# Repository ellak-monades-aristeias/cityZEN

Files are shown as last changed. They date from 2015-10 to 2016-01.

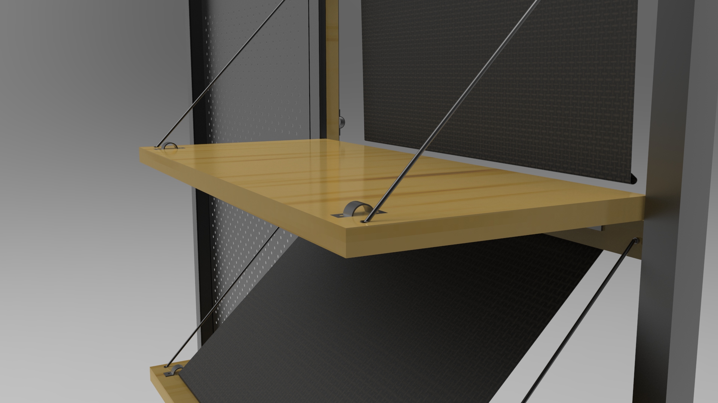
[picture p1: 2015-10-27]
bench/3d model/φωτορεαλιστικη απεικονιση/render.39.jpg

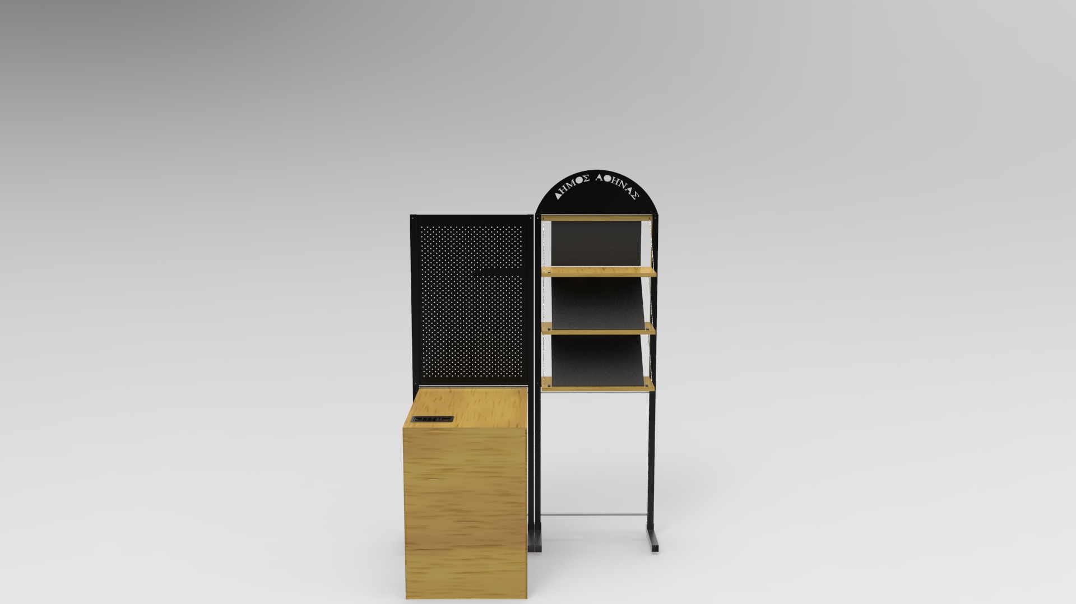
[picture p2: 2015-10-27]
bench/3d model/φωτορεαλιστικη απεικονιση/render.49.jpg

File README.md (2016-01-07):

# cityZEN

## Idea description

It's quite common to encounter hawkers on the streets, merchandising hand crafted objects, such us jewellery, vases or paintings. Using their craftsmanship skills is often a way for unemployed people with little if any income to increase their earnings. Unfortunately this activity is considered illegal and the legalisation surrounding it requires complex bureaucratic processes and fees, making it essentially inaccessible for them.

The legislators do not consider the aforementioned target group to be desirable, but they rather try to eliminate any such type of merchandising in fear of extensive profiteering from mischievous behaviour. The unfair competition between the pedlars and shop owners, the unregistered earnings of the pedlars, as well as the distortion of the cityscapes are, amongst others, the main reasons which increase the complexity of this way of merchandising. Identifying this gap sparked the idea for the creation of a system that allows unemployed people with craftsmanship skills to reach the market easily, in a way that can benefit both the merchants and the municipality. 

CityZEN proposes, on the one hand, a municipal service responsible for all legal, space, technical and curating issues, including the management of the merchants who use the service and the setting up the stalls. On the other hand, this project proposes a design of a versatile bench to unify the aesthetics and enable the beneficiaries to showcase their products.

The envisioned benefits are multifaceted: For the unemployed this service can help not only to increase their income but also to consider alternative careers. It is important to mention that the service is not intended to be provided for hawkers with high earnings but rather as an initial support for them to grow out of illegality and transform into established merchants. At the same time, the municipalities' identity is branded, the aesthetics of the cityscapes are improved and illegal merchandising can be better controlled.

## Η ιδέα

Πολλές φορές στις πόλεις μας τυχαίνει να βλέπουμε μικροπωλητές στα πλαϊνά των
πεζοδρόμων και των πλατειών να εμπορεύονται χειρότεχνα αντικείμενα, όπως
κοσμήματα, βαζάκια, πίνακες ζωγραφικής και άλλα παρόμοια είδη. Πρόκειται
συνήθως για ανθρώπους με χαμηλά ή μηδενικά εισοδήματα, συνήθως άνεργους, που
έχουν κάποιο ταλέντο και γνώσεις στην δημιουργία έργων χειροτεχνίας και
αναζητούν τρόπο να εκμεταλλευτούν την ικανότητά τους αυτήν προς όφελός τους.

Δυστυχώς η κοινωνία μας καθιστά ιδιαίτερα δύσκολο σε αυτούς τους ανθρώπους να
το πράξουν αυτό. Η πώληση αυτών των αγαθών σε δημόσιους χώρους είναι
παράνομη και για να νομιμοποιηθεί χρειάζονται επίπονες γραφειοκρατικές
διαδικασίες καθώς και καταβολή δυσμενών φόρων που καθιστούν το όλο εγχείρημα
μη συμφέρων, δεδομένου ότι η ποσότητα των πωλούμενων αντικειμένων είναι μικρή.

Η νομοθεσία μας καθιστά αυτό το είδος εμπορίου παράνομο, όμως, με αιτία τα εξής.
Καταρχήν, το γεγονός ότι επιτήδειοι θα μπορούσαν σε διαφορετική περίπτωση να
εκμεταλλευτούν δημόσιους χώρους για να έχουν **ανεξέλεγκτα κέρδη** χωρίς το
βάρος της ενοικίασης χώρου. Κατά δεύτερον, τον **αθέμιτο ανταγωνισμό** που
δημιουργείται μεταξύ των μικροπωλητών και των καταστημάτων που βρίσκονται
πλησίον τους, σε βάρος πάντα των καταστημάτων. Κατά τρίτον, την 
**αλλοίωση της εικόνας της πόλης**, που προκύπτει από το γεγονός ότι οι
πωλητές αυτοί χρησιμοποιούν αυτοσχέδιους τρόπους έκθεσης των εμπορευμάτων
τους, κάνοντας χρήση χαλιών, μουσαμάδων, χαρτόκουτων, κουβάδων, και άλλων
παρεμφερών αντικειμένων, σε διατάξεις ακανόνιστες, χωρίς να δίνεται καμία
προσοχή στην αισθητική.

Η πρότασή μας επιχειρεί να δώσει μια βοήθεια σε αυτούς τους μικροπωλητές,
λαμβάνοντας υπόψιν τα παραπάνω προβλήματα που δημιουργούνται από την
δραστηριότητά τους και δίνοντας λύσεις για καθένα από αυτά μέσα σε ένα πλαίσιο
που είναι και νόμιμο αλλά και εξίσου εύκολο και συμφέρων για αυτούς. Η πρόταση
αυτή αποτελείται από μια δημοτική υπηρεσία η οποία είναι υπεύθυνη για την ρύθμιση
όλων των νομικών, χωροτεχνικών και διαδικαστικών θεμάτων που αφορούν το
στήσιμο πάγκων μικροπωλητών αποκλειστικά από ανέργους, καθώς και από το
σχέδιο ενός πολυμορφικού πάγκου που στόχο έχει να δώσει ομοιόμορφη αισθητική και
να αποφέρει οφέλη για τον δήμο.

Τα οφέλη από την χρησιμοποίηση της λύσης μας είναι πολύπλευρα. Για τους
ανέργους, η υπηρεσία αυτή μπορεί να βοηθήσει στην αύξηση του εισοδήματός τους,
αλλά παράλληλα και στην ενεργοποίησή τους να κάνουν κάτι παραγωγικό με
προοπτική εξέλιξης σε κανονική επιχείρηση. Να σημειωθεί εδώ ότι η υπηρεσία μας
είναι σχεδιασμένη έτσι ώστε να σταματάει να παρέχεται σε μικροπωλητές που
επιτυγχάνουν μεγάλα κέρδη, ωθώντας τους έτσι να εξελιχθούν σε κανονικούς επιχειρηματίες. 
Από την άλλη, για τους δήμους δίνεται η δυνατότητα προβολής μέσα
από το branding που ενσωματώνεται στην κατασκευή, αναβαθμίζεται η αισθητική της
πόλης και επιπλέον δίνεται δυνατότητα καλύτερου ελέγχου αυτού του είδους
επιχειρηματικής δραστηριότητας έτσι ώστε να μην δημιουργούνται ούτε προβλήματα
εκμετάλλευσης αλλά ούτε και αθέμιτου ανταγωνισμού. Επιπλέον, οι πάγκοι αυτοί
μπορούν να χρησιμοποιηθούν και σε άλλα εγχειρήματα, όπως οι λαϊκές αγορές,
επιφέροντας και πάλι αντίστοιχα οφέλη στις δημοτικές αρχές.

## Περιγραφή σχεδίου

### Υπηρεσία

Η προτεινόμενη υπηρεσία λειτουργεί ως εξής. 

1. Αρχικά, ο ενδιαφερόμενος άνεργος πολίτης απευθύνεται στον οικείο του δήμο
προκειμένου να εγγραφεί στην υπηρεσία.

2. Όντας εγγεγραμμένος, αποκτά το δικαίωμα να χρησιμοποιήσει έναν από τους
πάγκους πώλησης της υπηρεσίας. Για να αποκτήσει έναν πάγκο χρειάζεται να
κάνει αίτηση στον δήμο, προσκομίζοντας μια λίστα με τα αντικείμενα τα οποία
ενδιαφέρεται να πουλήσει, αναγραφόμενα με είδος και ακριβή ποσότητα.

3. Στην συνέχεια, ο δήμος από την πλευρά του εγκρίνει ή απορρίπτει το αίτημα.

4. Μετά την έγκριση, παρέχεται στον ενδιαφερόμενο ένας πάγκος, καθώς και
πρόσβαση στην διαδικτυακή εφαρμογή της υπηρεσίας, μέσω της οποίας ο
ενδιαφερόμενος μπορεί να εντοπίσει τις διαθέσιμες επιτρεπόμενες τοποθεσίες
εγκατάστασης του πάγκου και να κάνει κράτηση σε κάποια από αυτές. Η
κράτηση αυτή προτείνεται να έχει ένα ανώτατο συνολικό χρονικό όριο 25 ωρών
την εβδομάδα, προκειμένου να δίνεται ευκαιρία και σε άλλους συμμετέχοντες να
χρησιμοποιήσουν την ίδια τοποθεσία.

5. Κατά την πώληση, οι μικροπωλητές οφείλουν να χρησιμοποιούν την
ενσωματωμένη ταμειακή μηχανή του πάγκου για να καταγράφουν τα ποσά που
λαμβάνουν.

6. Με βάση την χρηματική απόδοση (που ορίζεται ως κέρδος ανά χρόνο), το
δικαίωμα χρήσης της υπηρεσίας μπορεί να αναστέλλεται στις περιπτώσεις όπου
α) υπάρχει πολύ μικρή απόδοση ή β) υπάρχει πολύ μεγάλη απόδοση, στην οποία
περίπτωση η υπηρεσία δίνει κάποια περαιτέρω βοήθεια στον μικροπωλητή για να
ανοίξει κανονική επιχείρηση. Με αυτόν τον τρόπο δίνεται κίνητρο στον
μικροπωλητή να προσπαθήσει για ένα καλό αποτέλεσμα. Παράλληλα βέβαια, για
την αποφυγή εισαγωγής ψεύτικων στοιχείων στην ταμειακή μηχανή, επιβάλλεται
είσπραξη ενός μικρού ποσοστού 5% των κερδών από τον δήμο, πράγμα το οποίο
παράλληλα καλύπτει κάποια λειτουργικά έξοδα της υπηρεσίας.

### Πάγκος

Ο πάγκος αποτελείται από 4 αποσπώμενα μέρη τα οποία μπορούν να συνδυαστούν σε
διάφορους σχηματισμούς.

Αριστερά υπάρχει μια ξύλινη επίπεδη κατασκευή η οποία στέκεται όρθια με μεταλλικά
στηρίγματα και πόδια και με ράφια τα οποία ανοίγουν. Τα ράφια διαθέτουν στο
πίσω μέρος ένα ελαστικό παραβάν το οποίο μπορεί να μετατοπιστεί από την κάτω
του μεριά έτσι ώστε να δημιουργήσει ένα επικλινές για προβολή βιβλίων ή
αντίστοιχων αντικειμένων.

Δεξιά αυτού του μέρους υπάρχει μια διάτρητη μεταλλική επιφάνεια ίδιων διαστάσεων
με το προηγούμενο μέρος η οποία στηρίζεται με τον ίδιο τρόπο και στην οποία οι
χρήστες μπορούν να προσαρμόσουν εξαρτήματα για διάφορες χρήσεις.
Στο πάνω μέρος προσαρμόζεται μια ημικυκλική επιφάνεια, επίσης μεταλλική, η οποία
φέρει το λογότυπο του δήμου σχεδιασμένο με τρύπες πάνω στην επιφάνεια. Το μέρος
αυτό διατίθεται σε 2 διαστάσεις, ενα μικρό που μπορεί να συνδυαστεί είτε με το μέρος
των ραφιών είτε με την διάτρητη επιφάνεια, και ένα μεγάλο που συνδυάζεται και με
τα 2 ταυτόχρονα και τα δένει μεταξύ τους.

Τέλος, στο κάτω μέρος ενός εκ των 2 κάτω μερών προσαρμόζεται ένας επίπεδος
πάγκος. Μέσα σε αυτόν ενσωματώνεται και η ταμιακή μηχανή, σε περίπτωση που η
κατασκευή πρόκειται να χρησιμοποιηθεί με βάση την υπηρεσία της πρότασής μας.

Το σχέδιο αυτό επιτρέπει μεγάλη προσωπικοποίηση, τόσο μέσω του σχεδιασμού του με
βάση την χρήση διάφορων μερών καθώς και μέσω του αυτοσχεδιασμού των χρηστών
του.

### Ταμειακή μηχανή

Η διεπαφή της ταμειακής μηχανής επιτυγχάνεται με μια μικρή οθόνη TFT και ένα
πληκτρολόγιο μεμβράνης. Μέσα από την εφαρμογή δίνεται στον χρήστη η
δυνατότητα να εκτελέσει δυο λειτουργίες. Πρώτον, να εισάγει μια καινούρια πώληση
που μόλις έκανε και δεύτερον, να εξετάσει το ιστορικό πωλήσεων και να λάβει
πληροφορίες για την απόδοσή του.

Οι πληροφορίες αποθηκεύονται όλες σε μια προσβάσιμη και αφαιρούμενη SD card η
οποία εξετάζεται από τις δημοτικές αρχές ανά τακτά χρονικά διαστήματα.
Η μηχανή λειτουργεί με μπαταρίες, οι οποίες θα πρέπει να αλλάζονται κάθε περίπου 3
μήνες από τις δημοτικές αρχές.

## Πλοήγηση στο repository

- bench/ | φάκελος με τα σχέδια που αφορούν το έπιπλο-πάγκο
 - 3d model/
     - Φωτορεαλιστική απεικόνιση | εικόνες του αντικειμένου από διάφορες οπτικές
     - finalbench3dmodel.3dm     | το τελικό 3d model
     - render.bip                | keyshot file από το οποίο παράχθηκαν τα render
 - Files for 3d print/
     - Σφυχτήρας συρματόσχοινου.{3dm,stl} | αρχείο για 3d εκτύπωση πλαστικών κομματιών
                                            που συγκρατούν το συρματόσχοινο
 - Files for lasercut/
     - Bench desk.{ai,svg,pdf,dwg} | αρχεία για την κοπή του ξύλου του πάγκου
     - Box for electronics.{ai,svg,pdf,dwg}  | αρχεία κοπής των μερών του κουτιού
                                               για τα ηλεκτρονικά
     - File for the drawers.{ai,svg,pdf,dwg} | αρχεία κοπής των ραφιών
     - Metal plate lasercut_label_keyboard   | αρχείο κοπής μεταλλικής πινακίδας
                                               καθώς και του πληκτρολογίου
  - Πληκτρολόγιο μεμβράνης/
     - Πληκτρολόγιο μεμβράνης.{ai,pdf,svg}   | πρόταση κατασκευής πληκτρολογίου μεμβράνης
  - read me.odt      | πληροφορίες για τα υλικά και τη συντήρηση της κατασκευής
  - Οδηγίες κατασκευής.{ai,svg,pdf}  | φύλλο οδηγιών κατασκευής ενός πρωτοτύπου
- cash register/ | φάκελος με τα σχέδια που αφορούν την ηλεκτρονική ταμιακή μηχανή
 - electronics.fzz         | διάγραμμα καλωδιώσεων και PCB
 - documentation.{odt,pdf} | τεκμηρίωση/σημειώσεις για το σχέδιο των ηλεκτρονικών
 - arduino_src/            | φάκελος με κώδικα για τον microcontroller του σχεδίου
     - cityzen_cash_register/cityzen_cash_register.ino | proof-of-concept κώδικας
- service/ | φάκελος με τα σχέδια της υπηρεσίας (storyboard, web service wireframes, κλπ)
 - web service screens.{ai,svg,pdf} | Wireframes του web service
 - storyboard greek.{ai,svg}        | Το storyboard της υπηρεσίας
 - cashier screens.{ai,pdf,svg}}    | σχεδίαση οθονών της ταμειακής μηχανής
 - read me.odt                      | περιγραφή συμπεριφοράς συστήματος και παροχής υπηρείας
- cost estimation.fods               | υπολογισμός κόστους υλοποίησης
- Ταυτότητα συστήματος{.pdf,-01.png} | αφίσα ταυτότητας συστήματος
- LICENSE                            | άδεια χρήσης
- README                             | το παρόν έγγραφο

## File formats

- .fzz  | αρχείο του Fritzing (open software, open format) <http://fritzing.org>
- .3dm  | αρχείο του Rhino3D (closed software, open format) <http://www.rhino3d.com/opennurbs>
 - μπορεί να ανοιχτεί με το Blender <https://www.blender.org/>
- .ai   | αρχείο Adobe Illustrator (closed software, closed format), PDF compatible
 - ανοίγει με Inkscape καθώς και οποιονδήποτε PDF Viewer
- .svg  | Scalable Vector Graphics (open format)
 - ανοίγει με Inkscape
- .odt  | Open Document Text (open format)
 - ανοίγει με LibreOffice
- .fodt | Flat Open Document Text (open format)
 - ανοίγει με LibreOffice
- .fods | Flat Open Document Spreadsheet (open format)
 - ανοίγει με LibreOffice
- .ino  | Arduino IDE project source code (plain text)

## Σε ποίους απευθύνεται - Κοινότητες Χρηστών - Προγραμματιστών(Developers) ##

Το έργο cityZEN, ως υπηρεσία, απευθύνεται σε δημοτικές αρχές που επιθυμούν να
παρέχουν την εν λόγω υπηρεσία στους δημότες τους. Η υπηρεσία η ίδια απευθύνεται
σε πολίτες που διαθέτουν κάρτα ανεργίας και ασχολούνται με μικρο-κατασκευές που
επιθυμούν να πουλήσουν προκειμένου να ενισχύσουν το εισόδημά τους.

Ως έργο ανοιχτου σχεδιασμού/κώδικα, το cityZEN απευθύνεται σε βιομηχανικούς σχεδιαστές
που πιθανόν να θέλουν να επεκτείνουν την ιδέα ή και να χρησιμοποιήσουν μέρη της σε
διαφορετικά προϊόντα.

## Κόστος ##

Το κόστος υλοποίησης υπολογίζεται ως εξής:
* Σταθερό εφάπαξ κόστος υλοποίησης λογισμικού: 6000 €
* Κατασκευή μιας ολοκληρωμένης μονάδας: 750 €
* Κατασκευή 10 μονάδων (τιμή ανά μονάδα): 573 €
* Κατασκευή 100 μονάδων (τιμή ανά μονάδα): 388 €

Πιο αναλυτικές πληροφορίες για το κόστος βρίσκονται στο αρχείο
[cost estimation.{fods,pdf}](https://github.com/ellak-monades-aristeias/cityZEN/tree/master/cost estimation.pdf)

Για την χρήση του έργου το μοναδικό κόστος είναι το κόστος των αναλώσιμων,
δηλαδή 4 μπαταρίες ΑΑ που απαιτεί η ταμιακή μηχανή, καθώς και μια SD card
για την καταγραφή των δεδομένων (20-30 € συνολικά).

## Issues

Τυχών προβλήματα στο σχέδιο θα πρέπει να αναφέρονται στο
https://github.com/ellak-monades-aristeias/cityZEN/issues

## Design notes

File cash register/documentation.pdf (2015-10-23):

# Τεκμηρίωση ηλεκτρονικού συστήματος καταγραφής πωλήσεων

## Εξαρτήματα

- 1x Atmega 2560
- 1x DS1307 RTC
- 1x Coin Cell Battery Holder 12mm PTH
- 1x 32.768 kHz Crystal
- 1x 16 MHz crystal
- 1x L7805 Voltage regulator
- 1x L7803 Voltage regulator
- 4x electrolytic capacitors 100nF
- 2x ceramic capacitors 22pF
- 1x 4050 hex non-inverted buffer
- 1x SD card socket SMD
- 2x 220 kΩ resistors SMD
- 1x 10 kΩ resistor SMD
- 1x 2.2" 18-bit color TFT LCD display with microSD card breakout
- 1x AVR ICSP 6-pin header
- 1x pin header 1x8 SMD
- 1x 4 AA Battery Holder with On/Off Switch
- 1x custom membrane keypad

## Σημειώσεις

- Ο επεξεργαστής έχει επιλεχθεί με βάση το μέγεθος της μνήμης που διαθέτει, καθώς τα γραφικά στην οθόνη χρειάζονται αρκετή μνήμη. Παράλληλα, την επιλογή επηρέασε και η διαθεσιμότητα καθώς μικρότερα μοντέλα όπως ο atmega 644 και ο atmega 1280 είναι πιο δυσεύρετα στην αγορά.
- Το RTC (real-time clock) υπάρχει για να υποστηρίζεται η καταγραφή της ακριβούς ημερομηνίας και ώρας της κάθε πώλησης.
- Οι voltage regulators χρειάζονται για να παρέχουν γραμμές 5V και 3.3V χρησιμοποιώντας 4xAA μπαταρίες στη σειρά, οι οποίες κανονικά μας δίνουν 6V τάση.
- Το ολοκληρωμένο 4050 υποστηρίζει την πτώση των γραμμών δεδομένων από τα 5V του atmega στα 3.3V που απαιτεί η SD card.
- H microSD της οθόνης είναι χρήσιμη για την αποθήκευση γραφικών (εικόνων, γραμματοσειρών, κλπ) τα οποία είναι υπερμεγέθη για να αποθηκευτούν στην μνήμη του προγράμματος του atmega. Στο σενάριο χρήσης που έχουμε σκεφτεί, η κάρτα αυτή εγκαθίσταται από τον κατασκευαστή και δεν αφαιρείται από τους χρήστες, παρέχοντας ουσιαστικά read-only αποθηκευτικό χώρο για τα γραφικά.
- Ο 1x8 pin header χρησιμοποιείται για την σύνδεση του πληκτρολογίου. Το πληκτρολόγιο πρέπει να είναι 5x3 με κάθε γραμμή και κάθε στήλη να είναι προσβάσιμη με ένα καλώδιο.

## Προδιαγραφές μπαταριών

- 4x AA, Alkaline, 1.5V, 2800 mAh
- 1x CR1220, Li-MnO2

, 3.0V, 40mAh

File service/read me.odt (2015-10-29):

Αυτό το αρχείο περιγράφει την συμπεριφορά των σελίδων καθώς και τα στοιχεία χρήσης του συστήματος, όπως έχει οραματιστεί η ομάδα

WEBSERVICE PAGES

ΣΥΜΠΕΡΙΦΟΡΑ ΣΥΣΤΗΜΑΤΟΣ

LOGIN:Γίνεται μέσω ενός μοναδικού κωδικού για κάθε χρήστη, ο οποίος ορίζεται από την υπηρεσία που του δίνει πρόσβαση.

Θεωρώντας ότι η λίστα προϊόντων καθώς και τα προσωπικά στοιχεία του χρήστη είναι ήδη καταχωρημένα(από την αίτηση του για την υπηρεσία),όταν ο χρήστης κάνει login στην υπηρεσία ,τα στοιχεία του είναι ήδη διαθέσιμα.

LANDING PAGE: Η σελίδα αυτή επιτρέπει στο χρήστη την πλοήγηση του στην υπηρεσία,η οποία ορίζεται σε τρία στάδια

Α. Διαμόρφωση πάγκου: Ο χρήστης μπορεί να μορφοποιήσει τον πάγκο του ανάλογα με τις ανάγκες του . Κάθε χρήστης έχει όριο στους τρεις καμβάδες , είτε αυτοί είναι με διάτρητες μονάδες είτε με βασικές (κάθε καμβάς προσφέρεται για την μορφοποίηση μίας μονάδας)

Ο χρήστης μπορεί να προσθέσει καμβάδες μέσω του πλήκτρου +. Σε κάθε καμβά ανάλογα με το είδος του χρήστης μπορεί να επιλέξει :

Για το σύστημα ραφιών :

-χρώμα υφάσματος και υλικό ,

-λοιπά εξαρτήματα (πινακίδα, καλάθια)

Για το διάτρητο σύστημα: (κρεμάστρες, ράφια)

Εφόσον έχει εισέλθει σε ένα καμβά ή μία επιλογή , οι υπόλοιπες εμφανίζονται σε χαμηλότερη ορατότητα (opacity) , σε δεύτερο πλάνο. Τα επιλεγμένα αντικείμενα σηματοδοτούνται από ένα κίτρινο σημάδι στην άκρη της επιλογής

Τα στοιχεία διαμόρφωσης πηγαίνουν στην υπηρεσία όπου συναρμολογούνται οι πάγκοι.

Β. Καταχώρηση Κράτησης

Ανάλογα με το Δήμο στον οποίο κατοικεί ο χρήστης μπορεί να επιλέξει μεταξύ των διαθέσιμων θέσεων για συγκεκριμένη ημερομηνία και ώρα. Όταν κατοχυρωθεί επιλογή για ένα στοιχείο κράτησης, στα υπόλοιπα στοιχέια εμφανίζονται οι διαθέσιμες επιλογές , εφοσον υπάρχουν (π.χ. Ωράρια και ημερομηνίες για τα οποία είναι διαθέσιμες οι αναφερόμενες θέσεις ή θέσεις που είναι διαθέσιμες στις αναφερόμενες ώρες.)

Εφόσον γίνει η κράτηση , ο δήμος λαμβάνει το αίτημα και αναλαμβάνει την εγκατάσταση των πάγκων στην επιλεγμένη θέση. Η εγκατάσταση των πάγκων μπορεί να γίνεται σε ωριαία, ημερίσια η εβδομαδιαία βάση ανάλογα με τις δυνατότητες του εκάστοτε Δήμου.

Γ. Στατιστικά στοιχεία

Ο χρήστης μέσω του webservice έχει πρόσβαση στα στατιστικά στοιχεία που αφορούν την απόδοση του. Πιο συγκεκριμένα ο χρήστης οφείλει να καταγράφει τα ποσά που εισπράττει από την πώληση των αντικειμένων . Αυτό συμβαίνει γιατί κατά την προτεινόμενη χρήση του συστήματος υπάρχει μια συμβολική τιμαλφή που επιστρέφεται στο δήμο για την υποστήριξη της υπηρεσίας αλλά και για την επιβράβευση με επιπλέον ενίσχυση ενός χρήστη με προϊόντα μεγάλης εμπορικής αξίας, όπως ορίζεται από τα στατιστικά τους

CASHIER REGISTRY PAGES

Για την χρήση του συστήματος έχει διαμορφωθεί και μία low-cost ταμειακή μηχανή , με δύο λειτουργίες

-Ταμείο

Η χρήση του ταμείου εξυπηρετεί την καταγραφή δεδομένων για τη στατιστική ανάλυση. Ο χρήστης επιλέγει από την λίστα τα αντικείμενα προς πώληση και μέσω του πληκτρολογίου σημειώνει την τιμή στην οποία τα πούλησε.

Τα αντικείμενα που έχουν ήδη πουληθεί καταγράφονται με αχνό πορτοκαλί, και η τρέχουσα επιλογή με σκούρο πορτοκαλί

-Καλάθι

Στο καλάθι ο χρήστης μπορεί να έχει βραχυπρόθεσμη ενημέρωση για την πρόοδό του.

Πιο συγκεκριμένα μπορεί να δει τα χρήματα που έχει λάβει συνολικά για την μέρα καθώς και κάποια στατιστικά στοιχεία ανά ώρα.

Αυτό συμβαίνει γιατί η ταμιακή δεν επικοινωνεί άμεσα με το web service αλλά υπάρχει μια ετεροχρονισμένη ενημέρωση στοιχείων όταν καταχωρηθούν τα δεδομένα που βρίσκονται αποθηκευμένα στην sd card της ταμειακής με το σύστημα (sync). Με αυτό τον τρόπο όμως επιτρέπεται στον χρήστη να έχει και πιο άμεση εικόνα των κερδών του

Η γενική πλοήγηση πραγματοποιείται με της επιλογές τύπου joystick ενώ υπάρχουν και δύο κουμπιά επιβεβαίωσης και ακύρωσης.

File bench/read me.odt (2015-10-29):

Επιλογη υλικών

Ξύλο

-Plywood βερνικωμένο για αδιάβροχη προστασία

-mdf, επίσης βερνικωμένο, Στα σημεία επαφής με τα μεταλλικά πόδια καθώς και για την κατασκευή του κουτιού ηλεκτρονικών

Βίδες

Μέσα στα σχέδια δεν υπάρχουν πληροφορίες για τις βίδες

-Πάνω στο ξύλο χρησιμοποιούνται ξυλόβιδες [4,8 mm]

-Για το βίδωμα της ταμπέλας καθώς και των μεταλλικών στηριγμάτων μεταξύ τους χρησιμοποιείτε βίδα με παξιμάδι .

*Σε αντίθεση με το σχέδιο προτείνεται ο υπολογισμός κενού χώρου 1cm μεταξύ της ταμπέλας και του ξύλου

Πληκτρολόγιο Μεμβράνης

Για το πρωτότυπο προτείνεται πλαστικοποιημένο χαρτόνι

Συντήρηση

Η επιλογή των υλικών έχει γίνει με βάση την εύκολη κι γρήγορη αντικατάσταση κατεστραμμένων μελών. Έτσι η κατασκευή δέν είναι ανθεκτική στο χρόνο, αλλά είναι εύκολα αναπαράξιμη και επισκευαζόμενη (σε περίπτωση φθοράς ενός μέρους).

Πιο συγκεκριμένα η(υπολογισμένη διάρκεια ζωής της κατασκευής είναι 2 χρόνια αλλά εξαρτάτε απο τη χρήση του συστήματος

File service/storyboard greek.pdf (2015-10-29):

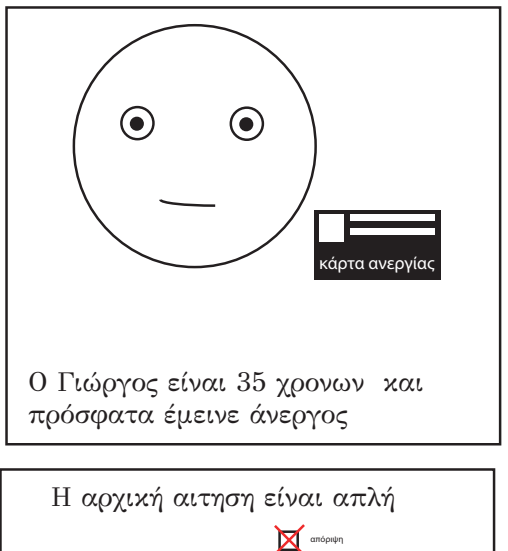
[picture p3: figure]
Ο Γιώργος είναι 35 χρονων και πρόσφατα έμεινε άνεργος; κάρτα ανεργίας; απόριψη; Η αρχική αιτηση είναι απλή
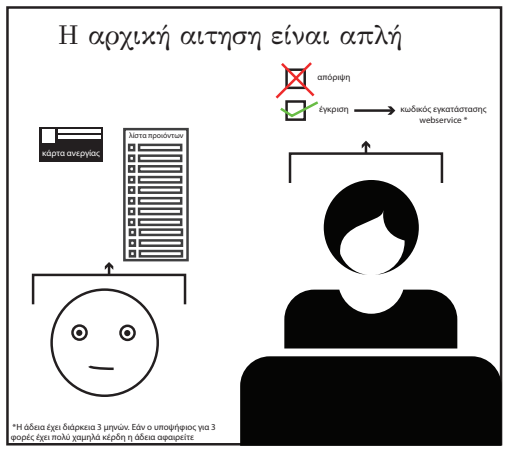
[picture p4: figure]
κάρτα ανεργίας; λίστα προιόντων; έγκριση; κωδικός εγκατάστασης; webservice *
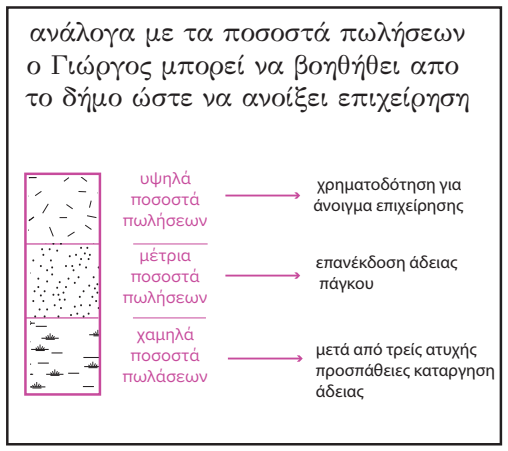
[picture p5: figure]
ο Γιώργος μπορεί να βοηθήθει απο το δήμο ώστε να ανοίξει επιχείρηση; υψηλά ποσοστά πωλήσεων; μέτρια ποσοστά πωλήσεων; χαμηλά ποσοστά πωλάσεων; χρηματοδότηση για άνοιγμα επιχείρησης; επανέκδοση άδειας πάγκου; μετά από τρείς ατυχής προσπάθειες καταργηση άδειας
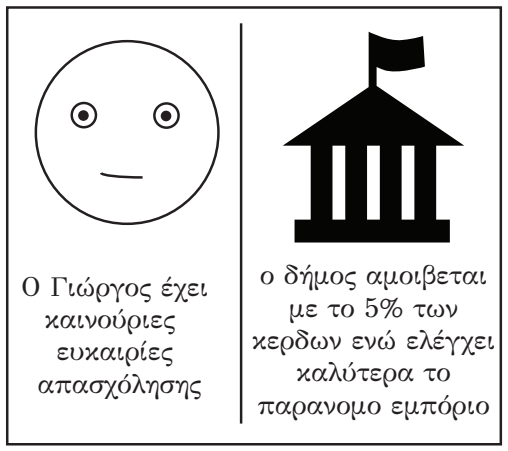
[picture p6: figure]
ο δήμος αμοιβεται με το 5% των κερδων ενώ ελέγχει καλύτερα το παρανομο εμπόριο; Ο Γιώργος έχει καινούριες ευκαιρίες απασχόλησης
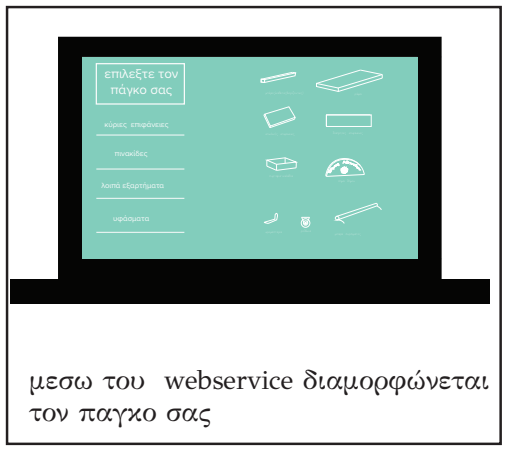
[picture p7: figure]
επιλεξτε τον πάγκο σας; κύριες επιφάνειες; λοιπά εξαρτήματα; µπάρες(καθετες&οριζοντιες); ράφια; επικλινής επιφανειες; διατρητες επιφανειες; συρταρια-καλάθια; σηµα δήµου; ροδάκια; µπαρα συρσιµατος κρεµασταρια; υφάσματα; πινακίδες; μεσω του webservice διαμορφώνεται τον παγκο σας

*Η άδεια έχει διάρκεια 3 μηνών. Εάν ο υποψήφιος για 3 φορές έχει πολύ χαμηλά κέρδη η άδεια αφαιρείτε

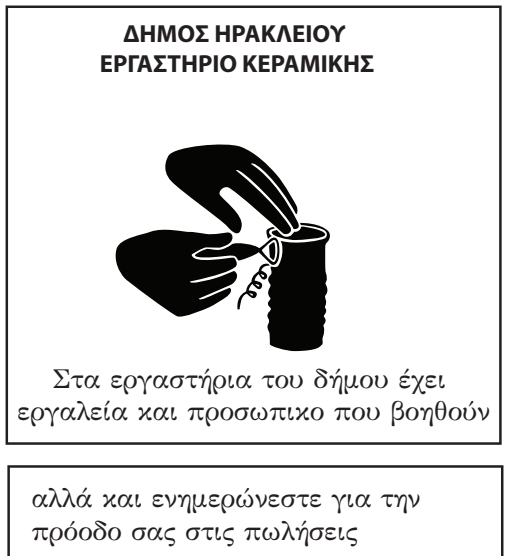
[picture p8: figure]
ΔΗΜΟΣ ΗΡΑΚΛΕΙΟΥ ΕΡΓΑΣΤΗΡΙΟ ΚΕΡΑΜΙΚΗΣ; Στα εργαστήρια του δήμου έχει εργαλεία και προσωπικο που βοηθούν; αλλά και ενημερώνεστε για την πρόοδο σας στις πωλήσεις

κράτηση
χώρου

ημερομηνία

ώρα

πληροφορίες
καλαθιού

μ.ο. κερδών
ανα ώρα

στατιστικα

# ΠΡΟΤΑΣΗ ΧΡΗΣΗΣ ΣΥΣΤΗΜΑΤΟΣ ΠAΓΚΟΥ

ΑΠΟ ΔΗΜΟΥΣ ΓΙΑ ΥΠΟΣΤΗΡΗΞΗ ΑΝΕΡΓΩΝ ΜΕ ΔΡΑΣΤΗΡΙΟΤΗΤΑ ΣΕ ΕΜΠΟΡΕΥΣΗΜΑ ΔΕΥΤΕΡΟΓΕΝΗ ΑΝΤΙΚΕΙΜΕΝΑ

δικαιώματα εικονιδίων
from the Noun Project
-Kayleigh Cavanaugh
-B Barrett
-Nikhileswar Jangala
-Clockwise
-Rémy Médard

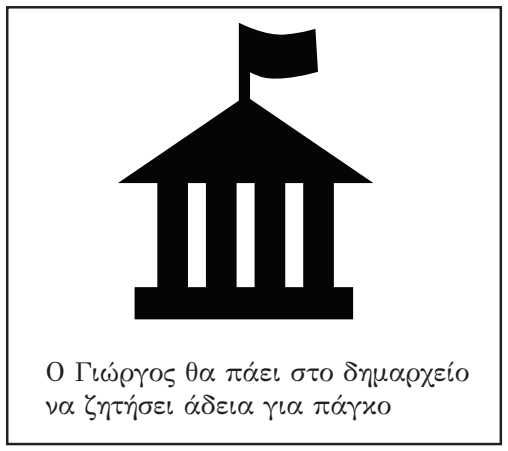
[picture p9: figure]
Ο Γιώργος θα πάει στο δημαρχείο να ζητήσει άδεια για πάγκο
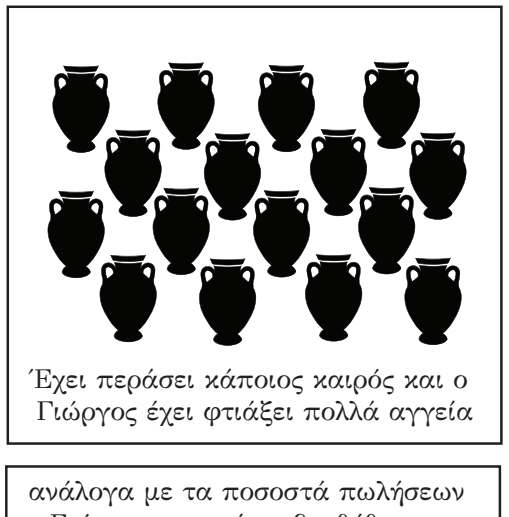
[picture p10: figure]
Έχει περάσει κάποιος καιρός και ο Γιώργος έχει φτιάξει πολλά αγγεία; ανάλογα με τα ποσοστά πωλήσεων
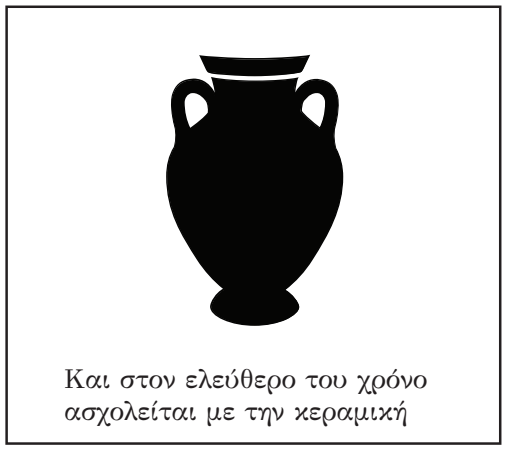
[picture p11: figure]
Και στον ελεύθερο του χρόνο ασχολείται με την κεραμική

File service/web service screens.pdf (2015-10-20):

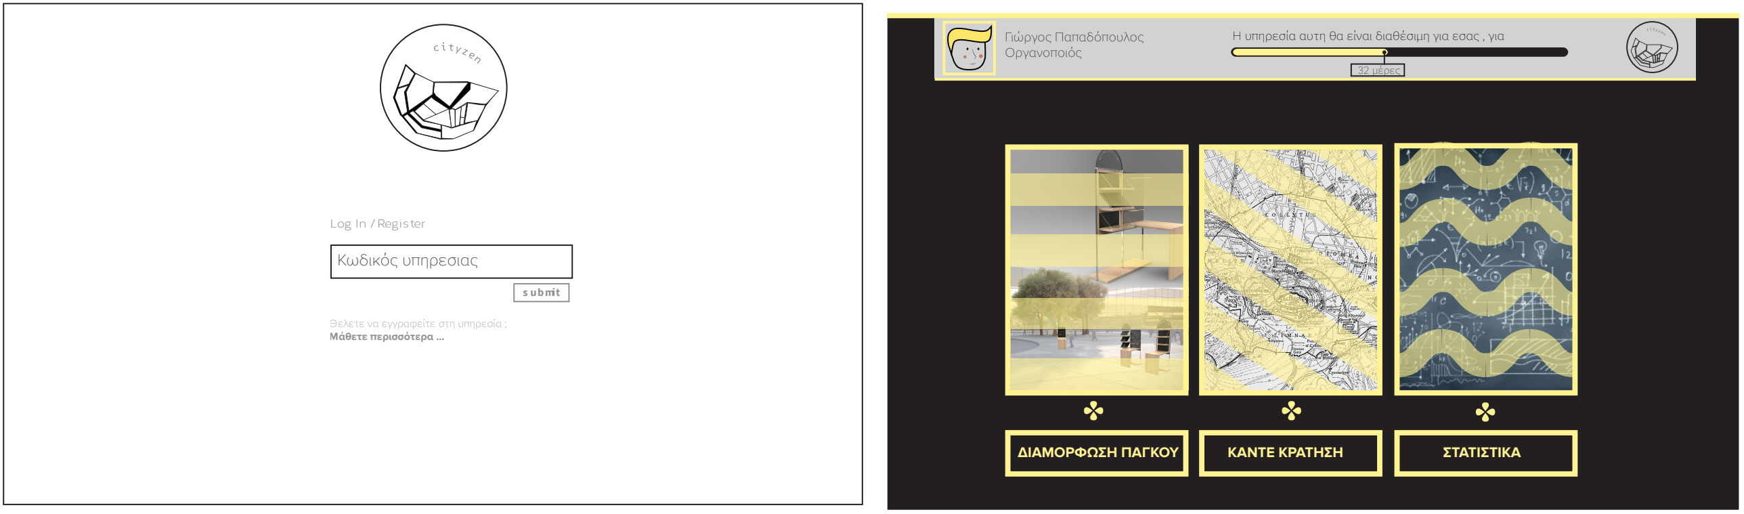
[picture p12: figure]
Γιώργος Παπαδόπουλος Οργανοποιός; s ubmit; Log In /Register; Κωδικός υπηρεσιας; Θελετε να εγγραφείτε στη υπηρεσία ; Μάθετε περισσότερα ...; 32 μέρες

Η υπηρεσία αυτη θα είναι διαθέσιμη για εσας , για

submit

Log In / Register

## Κωδικός υπηρεσιας

Θελετε να εγγραφείτε στη υπηρεσία ; Μάθετε περισσότερα ...

s ubmit

Log In /Register

## Κωδικός υπηρεσιας

Θελετε να εγγραφείτε στη υπηρεσία ; Μάθετε περισσότερα ...

Μη έγκυρος κωδικός

Παρακαλούμε ξαναδοκιμάστε ή συμβουλευτείτε το πλησιέστερο ΚΕΠ.

x

ok

ΔΙΑΜΟΡΦΩΣΗ ΠΑΓΚΟΥ | ΚΑΝΤΕ ΚΡΑΤΗΣΗ | ΣΤΑΤΙΣΤΙΚΑ

Γιώργος Παπαδόπουλος
Οργανοποιός

Η υπηρεσία αυτη θα είναι διαθέσιμη για εσας , για

### ΔΙΑΜΟΡΦΩΣΗ ΠΑΓΚΟΥ

32 μέρες

+

ΒΑΣΙΚΟΣ ΠΑΓΚΟΣ
διάτρητος

ράφια

υλικό

χρώμα

ΥΦΑΣΜΑΤΑ

ΚΡΕΜΑΣΤΡΕΣ

ΛΟΙΠΑ

4 cm

25 cm

πινακίδα

ραφια

καλάθια

Γιώργος Παπαδόπουλος
Οργανοποιός

Η υπηρεσία αυτη θα είναι διαθέσιμη για εσας , για

### ΔΙΑΜΟΡΦΩΣΗ ΠΑΓΚΟΥ

32 μέρες

+

ΒΑΣΙΚΟΣ ΠΑΓΚΟΣ
διάτρητος

ράφια

υλικό

χρώμα

ΥΦΑΣΜΑΤΑ

ΚΡΕΜΑΣΤΡΕΣ

ΛΟΙΠΑ

4 cm

25 cm

πινακίδα

ραφια

καλάθια

Γιώργος Παπαδόπουλος
Οργανοποιός

Η υπηρεσία αυτη θα είναι διαθέσιμη για εσας , για

### ΚΑΝΤΕ ΚΡΑΤΗΣΗ

32 μέρες

### ΔΗΜΟΣ ΑΘΗΝΑΙΩΝ

Επιλέξτε θέση

Επιλέξτε ημερομηνία

Επιλέξτε ώρα

### επιβεβαίωση κράτησης

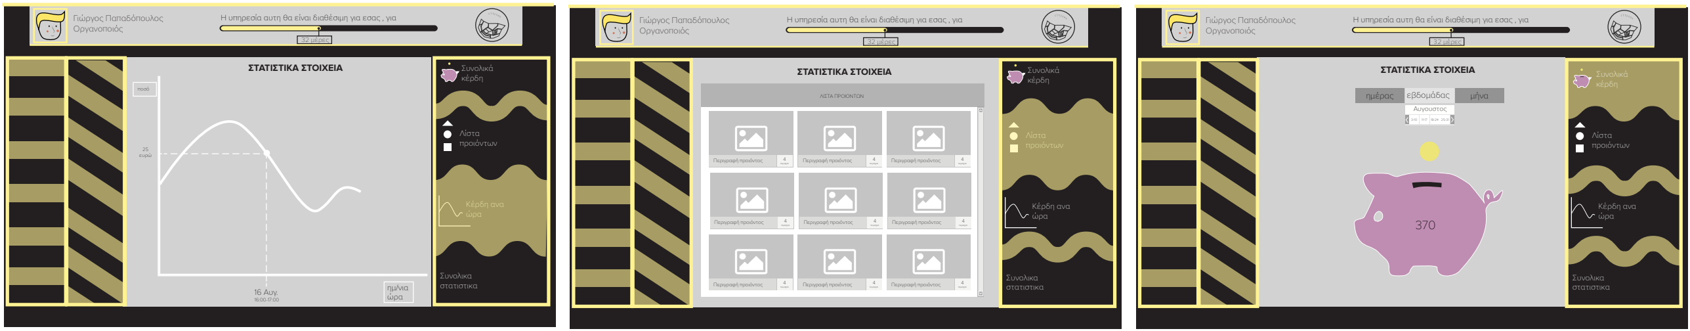
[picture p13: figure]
Γιώργος Παπαδόπουλος Οργανοποιός; ΣΤΑΤΙΣΤΙΚΑ ΣΤΟΙΧΕΙΑ; 32 μέρες; Συνολικά κέρδη; Λίστα προιόντων; Κέρδη ανα ώρα; Συνολικα; ημ/νια; στατιστικα; ώρα 16 Αυγ. 16:00-17:00; ποσό; Συνολικα στατιστικα; ΛΙΣΤΑ ΠΡΟΙΟΝΤΩΝ; Περιγραφή προιόντος; τεμαχια; 25 ευρώ; ημέρας; εβδομάδας; μήνα; Αυγουστος

Η υπηρεσία αυτη θα είναι διαθέσιμη για εσας , για Η υπηρεσία αυτη θα είναι διαθέσιμη για εσας , για

Η υπηρεσία αυτη θα είναι διαθέσιμη για εσας , για Γιώργος Παπαδόπουλος
Οργανοποιός

Η υπηρεσία αυτη θα είναι διαθέσιμη για εσας , για

### ΣΤΑΤΙΣΤΙΚΑ ΣΤΟΙΧΕΙΑ

32 μέρες

Συνολικά
κέρδη

Λίστα
προιόντων

Κέρδη ανα
ώρα

Συνολικα
στατιστικα

370

ΛΙΣΤΑ ΠΡΟΙΟΝΤΩΝ

Περιγραφή προιόντος | τεμαχια
4 | Περιγραφή προιόντος | τεμαχια
4 | Περιγραφή προιόντος | τεμαχια

4

ΣΥΝΟΛΙΚΑ ΚΕΡΔΗ

ημέρας | εβδομάδας | μήνα

ΚΕΡΔΗ ΑΝΑ ΩΡΑ

ημ/νια
ώρα 16 Αυγ.
16:00-17:00

ποσό

25
ευρώ

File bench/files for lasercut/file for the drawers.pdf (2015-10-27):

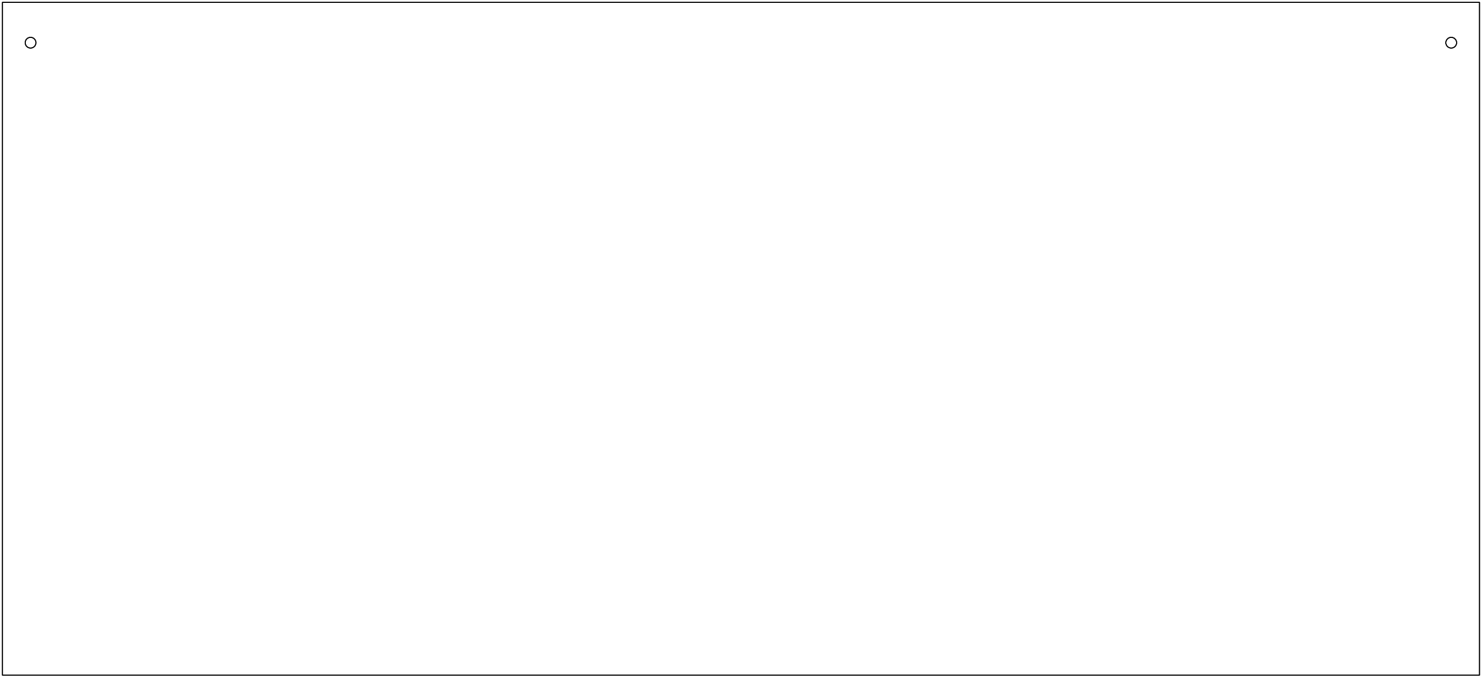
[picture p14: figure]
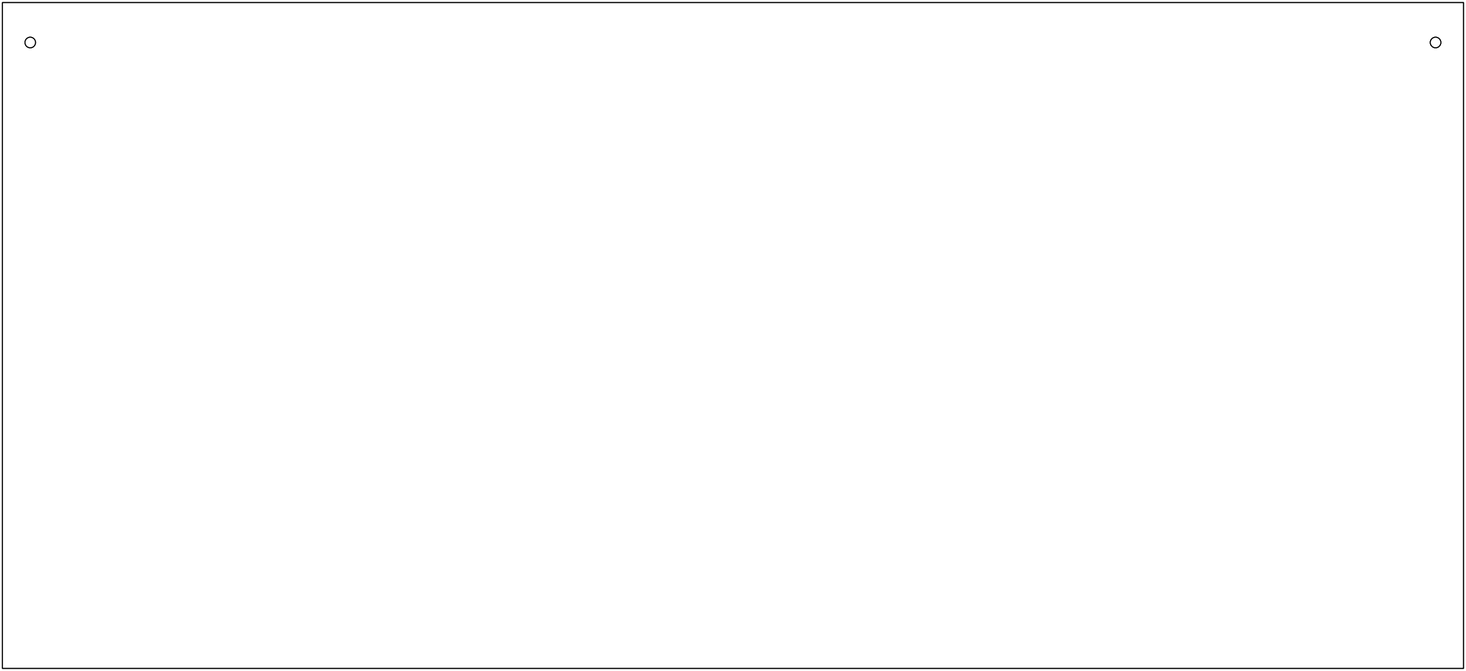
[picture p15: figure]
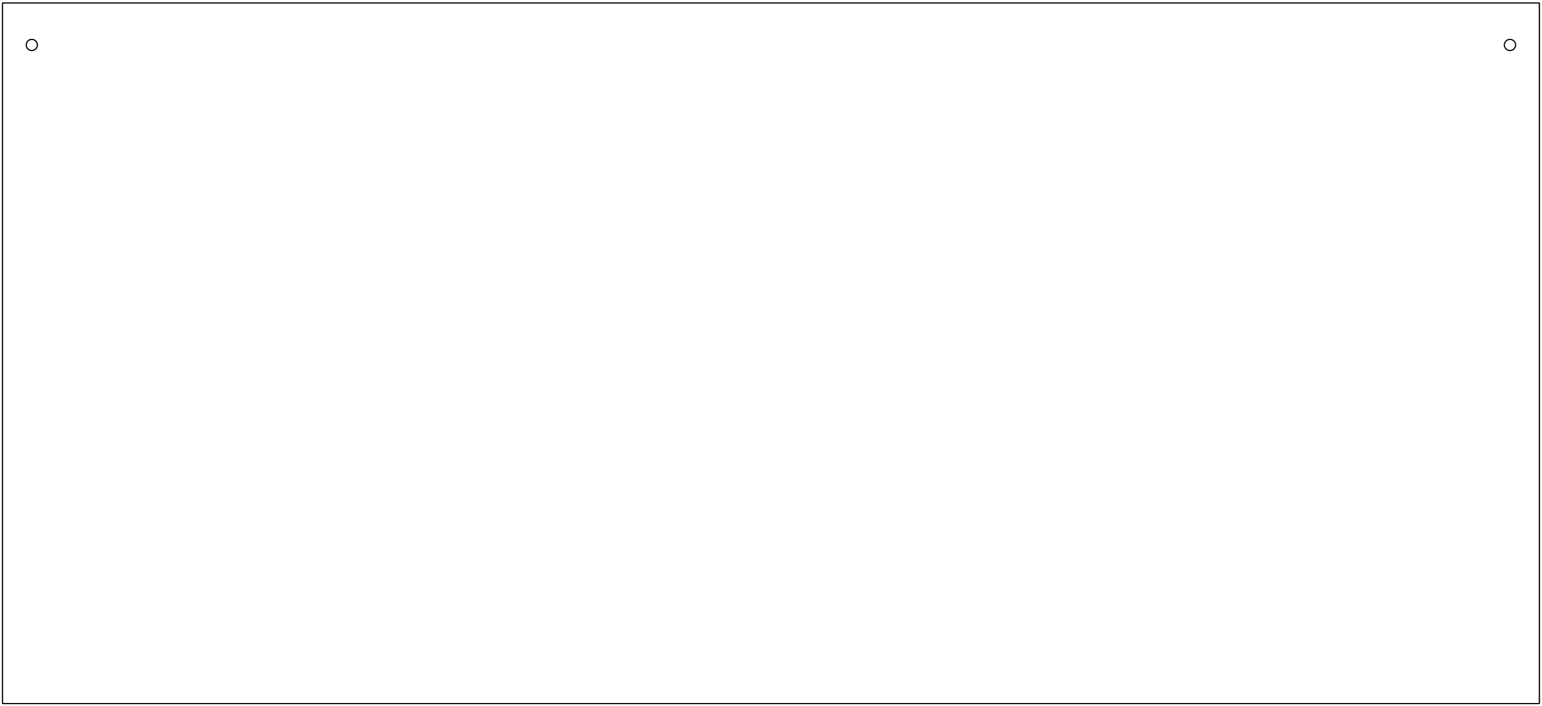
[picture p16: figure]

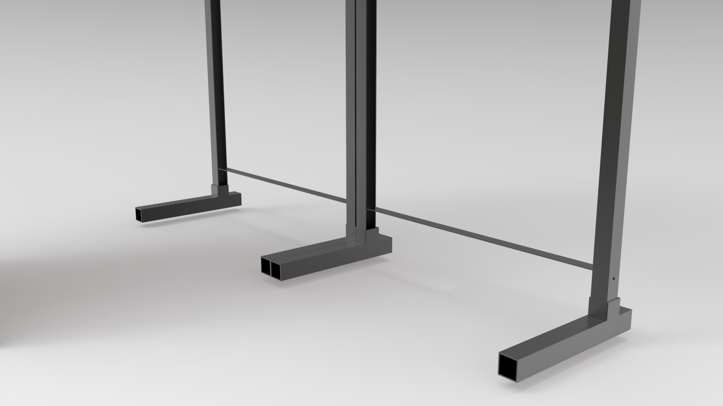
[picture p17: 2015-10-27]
bench/3d model/φωτορεαλιστικη απεικονιση/render.46.jpg

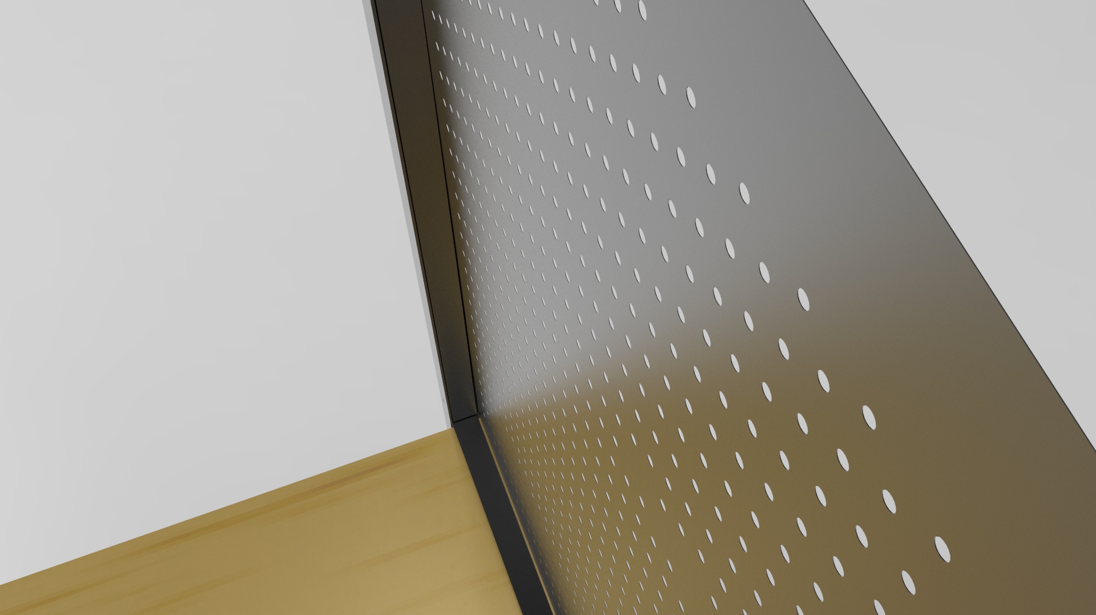
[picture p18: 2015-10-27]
bench/3d model/φωτορεαλιστικη απεικονιση/render.36.jpg

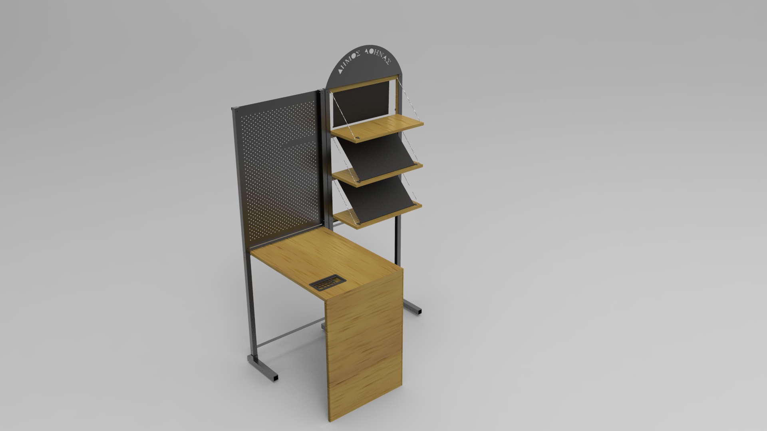
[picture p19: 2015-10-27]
bench/3d model/φωτορεαλιστικη απεικονιση/render.44.jpg

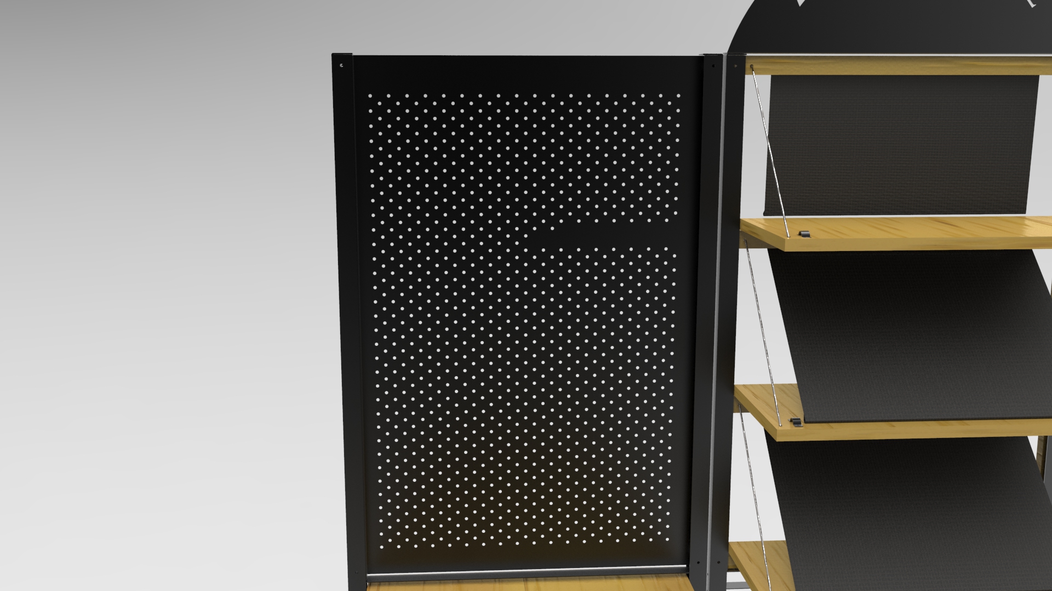
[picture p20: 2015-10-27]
bench/3d model/φωτορεαλιστικη απεικονιση/render.48.jpg

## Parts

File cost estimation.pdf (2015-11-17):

Πάγκος

Page 1

Περιγραφή | Χρήση | Διαστάσεις | Κόστος (€)
Λαμαρίνα ανοξείδωτο ατσάλι | 1,5 mm | 12 | 3 | 2
Λαμαρίνα διάτρητο ανοξείδωτο ατσάλι | | | | 30 | 15 | 10
Ξύλο MDF | Ραφιέρα, πάγκος, πόδι πάγκου | 18 mm | | 20 | 17 | 12
Ξύλο MDF | Κουτί ηλεκτρονικών | 3 mm | | 1 | 0.5 | 0.3
Ύφασμα lycra | Επικλινείς επιφάνειες | | | 3 | 1 | 0.5
Αλουμινένιες ράβδοι | Στήριξη υφάσματος από πίσω | | 3m | 3.5 | 1.5 | 1
Ξύλινες ράβδοι | | | 3m | 1 | 0.7 | 0.5
Ατσαλένιοι σωλήνες square | Πόδια | | 1m | 3 | 1.7 | 1.3
Ατσαλένιοι σωλήνες U-Profile | Πλαϊνά | | | 10 | 7 | 6
Βίδες | | | | 3 | 2.5 | 1.9
Πλαστικό PLA | | | | 2 | 2 | 0
Συρματόσχοινο | Κράτημα ραφιών | Φ 2 mm | 2.10m | 1.5 | 1.5 | 1
Μεντεσέδες ατσαλένιοι | | | 8 | 12 | 6 | 3
Εργατικά | 2 ημέρες | 100 | 80 | 50
κόψιμο ξύλου | | | | | | 180
Laser cutting | | | | 300 | 250 | 15
3d printing | | | | 10 | 5 | 0
| | | | | | 2
| | | Σύνολο | 512 | 394.4 | 286.5

### Ποσότητα /

Χρόνος | Κόστος για 10 (ανα τμχ)

Κόστος για
100 (ανα τμχ)

Επιγραφή, καπάκι πληκτρολογίου, ενωτικές ράβδοι ποδιών

0.3 m²

0.6 m²

1.8 m²
0.2 m²
0.6 m²

Τελείωμα υφάσματος στο κάτω μέρος του

3d-printed κράτημα σχοινιών των ραφιών

Ανοίγματα ραφιών, άνοιγμα ποδιού πάγκου

off the shelf εξαρτήματα αντί για 3d printing

Πάγκος

Page 2

Αιτιολογία μείωσης κόστους

Αλλαγή διαδικασίας

Βέλτιστη χρήση επιφάνειας υλικού και προμήθεια
Βέλτιστη χρήση επιφάνειας υλικού και προμήθεια. Για 1 & 10
αγοράζουμε σκέτη λαμαρίνα και γίνεται laser cut. Για 100 αγοράζουμε έτοιμα perforated Βέλτιστη χρήση επιφάνειας υλικού και προμήθεια

Βέλτιστη χρήση επιφάνειας υλικού και προμήθεια

Ταμειακή μηχανή

Page 3

Περιγραφή | Σύνδεσμος | | Κόστος (€)
4 x AA Battery Holder with On/Off Switch https://www.adafruit.com/products/830 | 1 | 2.6 | 2.49 | 2.18
L7805 Voltage Regulator 5V 1.5A | | 1 | 0.39 | 0.32 | 0.27
Voltage regulator LD1117 - 3.3V 800mA | | 1 | 0.39 | 0.32 | 0.27
Electrolytic Capacitor 16V 10uF | | 4 | 0.24 | 0.2 | 0.2
Ceramic capacitor 50V 22pF | http://grobotronics.com/50v-22pf.html | 2 | 0.04 | 0.02 | 0.01
SD Card Socket SMD | http://grobotronics.com/sd-socket-smd.html | 1 | 0.9 | 0.71 | 0.63
74HC4050 | http://grobotronics.com/74hc4050.html | 1 | 0.3 | 0.23 | 0.21
Resistor SMD 0805 10 kΩ | | 1 | 0.01 | 0.01 | 0.01
Resistor SMD 0805 2.2 kΩ | | 2 | 0.02 | 0.02 | 0.02
32.768 kHz Crystal | | 1 | 0.3 | 0.23 | 0.21
20 MHz Crystal | http://grobotronics.com/crystal-20mhz.html | 1 | 0.27 | 0.22 | 0.19
DS1307 Serial RTC | | 1 | 3.49 | 3.18 | 2.89
Coin Cell Battery Holder 12mm PTH | | 1 | 0.39 | 0.32 | 0.27
8 pin female SMD header | https://www.sparkfun.com/products/11543 | 1 | 0.86 | 0.8 | 0.72
2x3 pin shrouded header | https://www.sparkfun.com/products/10877 | 1 | 1.36 | 1.3 | 1.2
Atmega 256x | https://www.sparkfun.com/products/12906 | 1 | 9 | 8.9 | 8
| https://www.adafruit.com/products/1480 | 1 | 22 | 21 | 20.2
microSD card | 1 | 7.89 | 7.4 | 7.2

### Ποσότητα /

Χρόνος | Κόστος για 10 (ανα τμχ)

Κόστος για
100 (ανα τμχ)

http://grobotronics.com/voltage-regulatorl7805cv.html
http://grobotronics.com/voltage-regulatorld1117-3.3v.html
http://grobotronics.com/electrolyticcapacitor-16v-10uf.html

http://grobotronics.com/resistor-smd-0805-el.html
http://grobotronics.com/resistor-smd-0805-el.html
http://grobotronics.com/crystal-32.768-khz.html

http://grobotronics.com/ds1307-64-x-8-serial-rtc.html
http://grobotronics.com/coin-cell-batteryholder-12mm-pth.html

2.2" 18-bit color TFT LCD display with microSD card breakout - ILI9340 http://www.ebay.com/itm/Samsung-EVO-16GB-32GB-64GB-Micro-SD-SDHC-SDXC-48MB-s-UHS-I-Class10-Memory-Card-/121584748549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
var=&hash=item1c4f040805

Ταμειακή μηχανή

Page 4

Πληκτρολόγιο μεμβράνης | | 1 | 5 | 4 | 2
PCB διπλής όψης | http://www.f-pcb.gr | 1 | 32 | 27 | 15
| | Μερικό σύνολο, αξία ηλεκτρονικών | 87.45 | 78.67 | 61.68
Κολλήσεις | 1 ημέρα | 150 | 100 | 40
Υλοποίηση προγράμματος & testing | 15 ημέρες | 3000 | 300 | 30
| Σύνολο | 3237.45 | 478.67 | 131.68

http://www.technogrami.gr/index.php?option=com_content&view=article&id=19&catid=3&Itemid=52

Web service

Page 5

Περιγραφή | Ποσότητα / Χρόνος | Κόστος (€)
Στήσιμο βάσης δεδομένων | 2 ημέρες | 300
προγραμματισμός backend | 3 ημέρες | 450
προγραμματισμός βασικής διεπαφής | 4 ημέρες | 600
ενσωμάτωση χάρτη | 2 ημέρες | 300
προγραμματισμός λογικής προσωπικοποίησης πάγκου | 2 ημέρες | 300
προγραμματισμός οπτικοποίησης στατιστικών | 2 ημέρες | 300
Testing – bufgixing | 5 ημέρες | 750
| Σύνολο | 3000

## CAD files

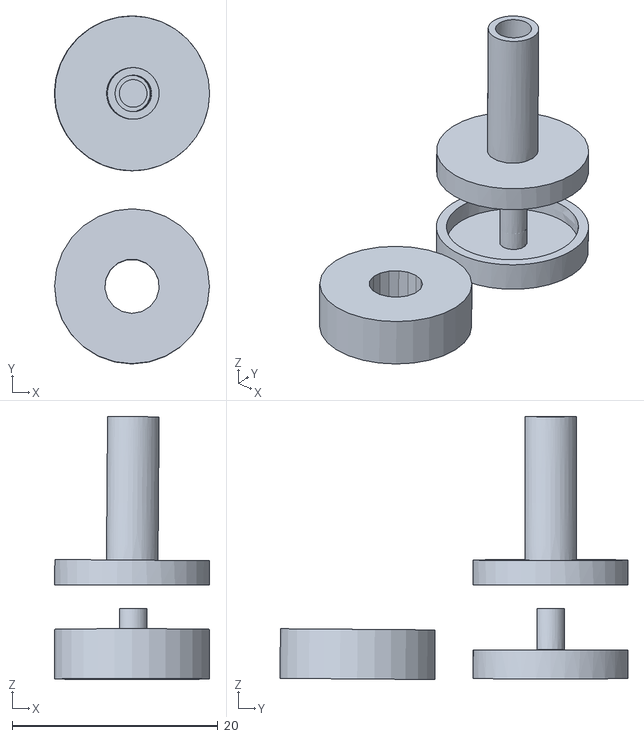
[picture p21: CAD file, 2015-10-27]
bench/files for 3d print/Σφυχτηρας συρματοσχοινου.stl
15.1 x 33.9 x 25.6

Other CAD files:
bench/files for lasercut/file for the drawers.dwg
bench/files for lasercut/box for electronics.dwg
bench/files for lasercut/bench desk.dwg
bench/files for lasercut/metal plate lasercut_label_keyboard.dwg
bench/files for 3d print/Σφυχτηρας συρματοσχοινου.3dm

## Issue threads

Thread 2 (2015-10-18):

bench: finalize instructions

gkiagia, 2015-10-18:
Should include at least:
* List of materials
* Cuts
* Holes
* Welds
* Assembly
* photos
* diagrams

Instructions should be available in odt and pdf formats

Closed 2015-11-17.

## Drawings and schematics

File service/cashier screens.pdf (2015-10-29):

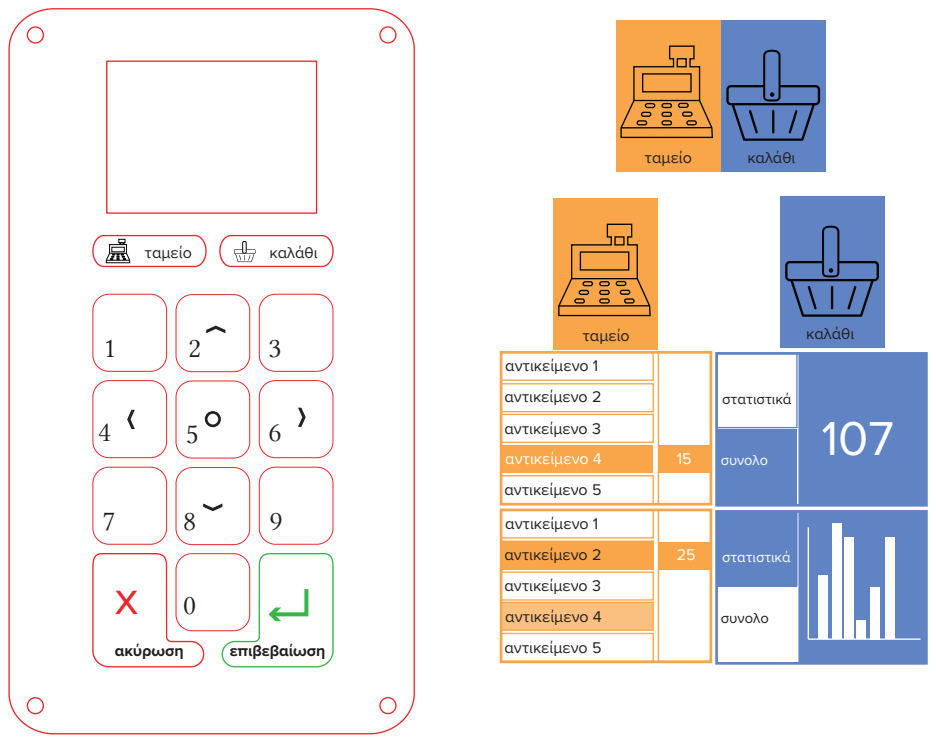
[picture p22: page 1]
ταμείο; καλάθι; ακύρωση; επιβεβαίωση; αντικείμενο 1; αντικείμενο 2; αντικείμενο 3; αντικείμενο 4; αντικείμενο 5; στατιστικά; συνολο

αντικείμενο 1 | | στατιστικά
αντικείμενο 2 | 25

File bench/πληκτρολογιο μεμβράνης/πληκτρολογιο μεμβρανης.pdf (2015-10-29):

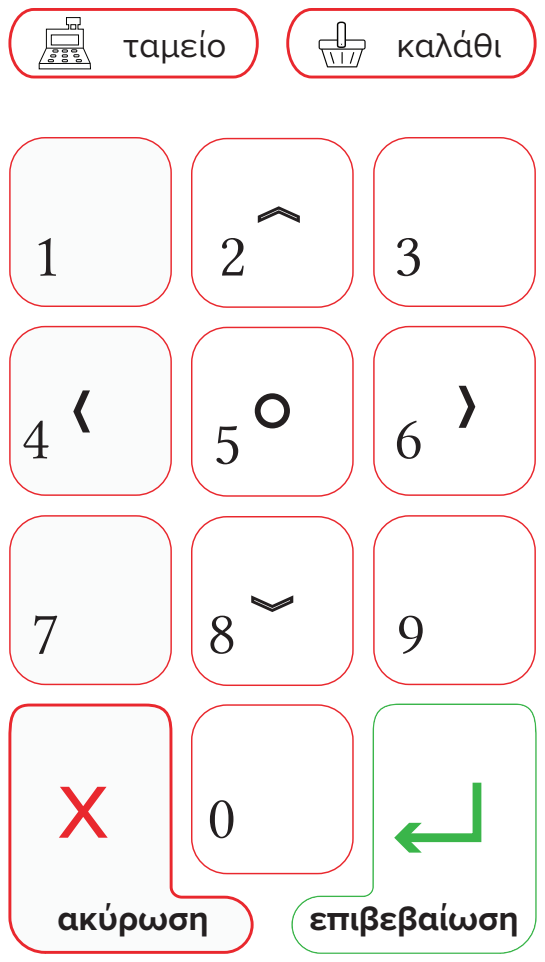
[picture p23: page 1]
ταμείο; καλάθι; ακύρωση; επιβεβαίωση

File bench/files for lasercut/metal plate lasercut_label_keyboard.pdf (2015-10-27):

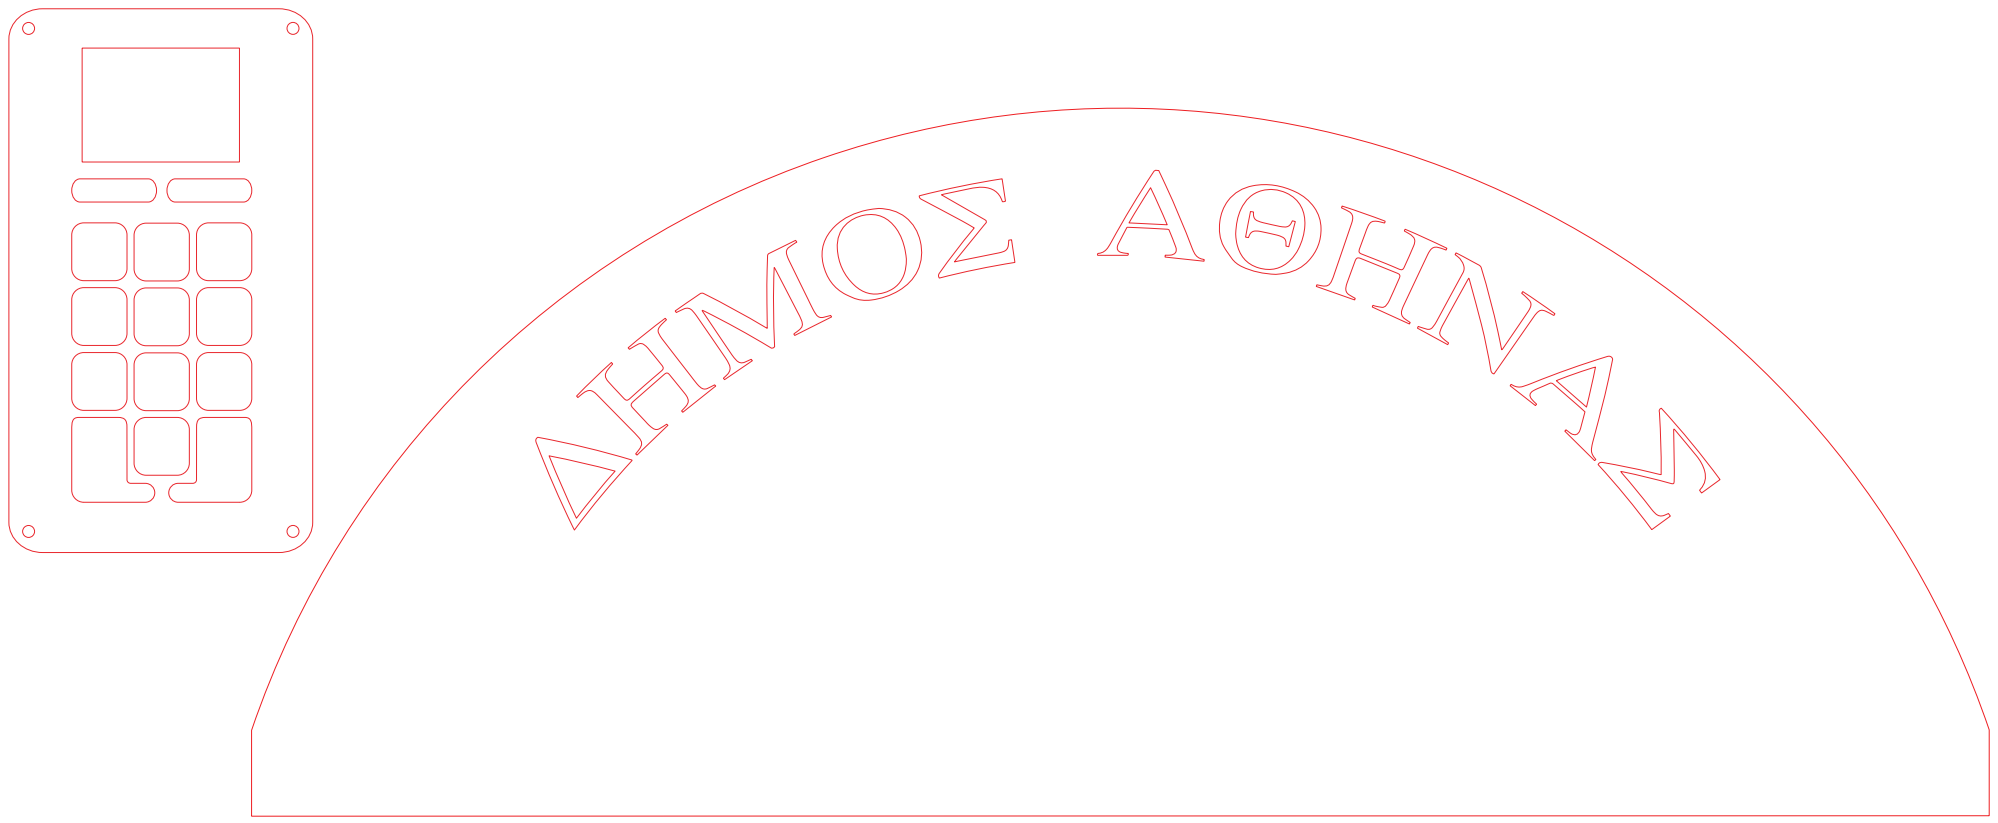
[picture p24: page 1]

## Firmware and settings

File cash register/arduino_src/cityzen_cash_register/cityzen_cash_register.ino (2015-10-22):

/*
    Proof of concept code for the cityZEN cash register machine

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
    You should have received a copy of the GNU General Public License
    along with this program.  If not, see <http://www.gnu.org/licenses/>.
*/

#include <SPI.h>
#include <SD.h>
#include <Keypad.h>
#include <Time.h>
#include <Wire.h>
#include <DS1307RTC.h>
#include <Adafruit_GFX.h>
#include <Adafruit_ILI9340.h>

#define TFT_BL     3   // PE5
#define TFT_CS     10  // PB4
#define TFT_RST    12  // PB6
#define MICROSD_CS 11  // PB5
#define SD_CS      5   // PE3
#define ATMEGA_SS  53
#define KEYPD_1    25  // PA3
#define KEYPD_2    26  // PA4
#define KEYPD_3    28  // PA6
#define KEYPD_4    27  // PA5
#define KEYPD_5    30  // PC7
#define KEYPD_6    29  // PA7
#define KEYPD_7    32  // PC5
#define KEYPD_8    31  // PC6

#define KEYPD_ROWS 5
#define KEYPD_COLS 3
char s_kpdKeys[KEYPD_ROWS][KEYPD_COLS] = {
  {'^','%','$'},
  {'1','2','3'},
  {'4','5','6'},
  {'7','8','9'},
  {'c','0','e'}
};
byte s_kpdRowPins[KEYPD_ROWS] = { KEYPD_1, KEYPD_2, KEYPD_3, KEYPD_4, KEYPD_5 };
byte s_kpdColPins[KEYPD_COLS] = { KEYPD_6, KEYPD_7, KEYPD_8 };
Keypad kpd = Keypad(makeKeymap(s_kpdKeys), 
    s_kpdRowPins, s_kpdColPins,
    KEYPD_ROWS, KEYPD_COLS);

SDClass userSD;

Adafruit_ILI9340 tft = Adafruit_ILI9340(TFT_CS, TFT_BL, TFT_RST);

void setup()
{
  Serial.begin(9600);
  pinMode(ATMEGA_SS, OUTPUT); // host slave select disabled
  SD.begin(MICROSD_CS);
  userSD.begin(SD_CS);
  tft.begin();
}

typedef enum { MODE_CASHIER, MODE_REVIEW } Mode;
Mode mode = MODE_CASHIER;
Mode old_mode = MODE_REVIEW;

void loop()
{
  char input = kpd.getKey();
  
  if (input == '^') {
    mode = MODE_CASHIER;
  } else if (input == '$') {
    mode = MODE_REVIEW; 
  }

  switch (mode) {
    case MODE_CASHIER:
      if (old_mode != MODE_CASHIER) {
        renderCashierScreen();
      }
      cashierScreen(input);
      break;
    case MODE_REVIEW:
      if (old_mode != MODE_REVIEW) {
        renderReviewScreen();
      }
      reviewScreen(input);
      break;
    default:
      break;
  }
  
  old_mode = mode;
}

String cashierAmount = "";

void renderCashierScreen()
{
  File itemsListFile;
  
  cashierAmount = "";

  tft.fillScreen(ILI9340_BLACK);
  tft.setCursor(0, 0);
  tft.setTextColor(ILI9340_WHITE);
  tft.println("Cashier");
  
  itemsListFile = userSD.open("items.txt", FILE_READ);
  if (itemsListFile) {
    while (itemsListFile.available()) {
     tft.println(itemsListFile.readStringUntil('\n'));
     // TODO: limit the list to the amount of lines and make it scrollable
    }
   
    itemsListFile.close(); 
  } else {
    tft.println("items.txt could not be opened");
  }
}

void cashierScreen(char input)
{
  // TODO: UI navigation

  if (input >= '0' && input <= '9') {
    // store the typed amounnt
    cashierAmount += input; 
  } else if (input == 'e') {
    storeTransaction();
  } else if (input == 'c') {
    cashierAmount = "";
  }
}

void print2digits(Stream & stream, int number)
{
  if (number >= 0 && number < 10) {
    stream.write('0');
  }
  stream.print(number);
}

void storeTransaction()
{
  tmElements_t tm;
  File transactionsFile = userSD.open("transactions.txt", O_WRITE | O_APPEND);
  
  RTC.read(tm);
  transactionsFile.print(tm.Year);
  print2digits(transactionsFile, tm.Month);
  print2digits(transactionsFile, tm.Day);
  transactionsFile.print('-');
  print2digits(transactionsFile, tm.Hour);
  print2digits(transactionsFile, tm.Minute);
  print2digits(transactionsFile, tm.Second);
  transactionsFile.print(" 0 "); //item code (hardcoded to 0 for demo)
  transactionsFile.print(cashierAmount);
  transactionsFile.print('\n');
  transactionsFile.close();
}

void renderReviewScreen()
{
  File transactionsFile;
  
  tft.fillScreen(ILI9340_BLACK);
  tft.setCursor(0, 0);
  tft.setTextColor(ILI9340_WHITE);
  tft.println("Review");
  
  transactionsFile = userSD.open("transactions.txt", FILE_READ);
  if (transactionsFile) {
    while (transactionsFile.available()) {
     tft.println(transactionsFile.readStringUntil('\n'));
     // TODO: render something better than the raw database file
    }
   
    transactionsFile.close(); 
  } else {
    tft.println("No transactions yet");
  }
}

void reviewScreen(char input)
{
  // TODO: scroll
}

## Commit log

2015-09-29 Import source files for various graphics
    [electronics.fzz]
2015-10-06 lasercut files: decoration, sides & leg details
2015-10-06 lasercut files: perforation & logo label
2015-10-06 move metal lasercut files in metal folder
2015-10-06 wood cut svg and dxf files
    [BENCHELECTRONICS2 [Converted].dxf, legs cut files [Converted].dxf, wood lasercut.dxf]
2015-10-07 lasercut files: add dxf for metal cuts
    [decoration_sides_legdetails.dxf]
2015-10-15 towards the end result
    [let's detail this design.3dm]
2015-10-22 cash register: finalize electronics pcb diagram
    [electronics.fzz]
2015-10-22 cash register: add proof of concept arduino code
2015-10-22 cash register: fix usage of SDA/SCL lines in pcb
    The DS1307 requires a two-wire interface which is only
    available on specific ports of the atmega.
    [electronics.fzz]
2015-10-22 cash register: add description & license header on arduino code
2015-10-23 cash register: convert documentation to flat odt and add battery specs
    flat odt works better with git diff...
2015-10-27 finalising deliverables
    [detailingdesign.3dm, let's detail this design.3dm]
2015-10-27 bench: remove old/unused files
    [let's detail this design.3dm]
2015-11-13 Add cost estimation in pdf format (and adjust ods to make it printable)

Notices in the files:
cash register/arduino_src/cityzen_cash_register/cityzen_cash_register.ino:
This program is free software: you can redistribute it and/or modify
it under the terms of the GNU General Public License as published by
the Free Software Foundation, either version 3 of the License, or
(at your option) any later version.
